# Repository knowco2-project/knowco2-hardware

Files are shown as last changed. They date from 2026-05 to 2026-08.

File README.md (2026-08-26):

# KnowCO2 Hardware

This repository contains the open hardware design files and mechanical references for the KnowCO2 indoor air quality monitor.

All original KnowCO2 hardware design files in this repository are released under the [CERN-OHL-S-2.0](LICENSE-HARDWARE) license.

## Hardware overview

The current KnowCO2 KC2-01 hardware design is built around third-party Adafruit modules and a custom KnowCO2 3D printed enclosure.

| Item | Description | Source |
|---|---|---|
| Adafruit Feather ESP32-S3 Reverse TFT | Main controller, display, Wi-Fi, USB-C power | Third-party module |
| Adafruit SCD-40/SCD-41 CO2 Sensor Breakout | CO2, temperature, and humidity sensor | Third-party module |
| STEMMA QT cable | I2C connection between Feather and sensor | Third-party cable |
| KnowCO2 enclosure | Custom 3D printed enclosure | Original KnowCO2 design files in this repository |

## Folders

| Folder | Contents |
|---|---|
| [enclosure/](enclosure/) | KnowCO2 3D enclosure design files |
| [docs/](docs/) | Documentation |
| [bom/](bom/) | Bill of materials |

## Third-party PCB/module CAD references

The Adafruit PCB/module CAD files are not maintained by KnowCO2. They are linked as mechanical references for fit checks, connector clearance, display alignment, button placement, sensor placement, and assembly planning.

- Adafruit Feather ESP32-S3 Reverse TFT:  
  https://github.com/adafruit/Adafruit_CAD_Parts/tree/main/5691%20Feather%20ESP32%20S3%20Reverse%20TFT

- Adafruit SCD-40/SCD-41 CO2 Sensor Breakout:  
  https://github.com/adafruit/Adafruit_CAD_Parts/tree/main/5187%20SCD-40%20C02%20Sensor

Third-party CAD files, board designs, product names, and trademarks remain the property of their respective owners.

## KnowCO2 enclosure files

The custom KnowCO2 enclosure files are included under [enclosure/](enclosure/).

The current enclosure design includes four printed parts:

| Part | Purpose |
|---|---|
| Main case | Main body for the Feather ESP32-S3 Reverse TFT |
| Main cover / front panel | Cover with display/button access for the main unit |
| Sensor case | Remote/secondary enclosure body for the SCD41 sensor module |
| Sensor cover | Cover for the SCD41 sensor enclosure |

## File formats

### Enclosure / 3D printed parts

| Format | Purpose |
|---|---|
| STEP (`.step` / `.stp`) | Preferred open CAD exchange format for modification and manufacturing |
| STL (`.stl`) | Print-ready mesh format for slicers |
| Shapr3D (`.shapr`) | Original source file, if included |
| PNG/JPG | Reference renders or assembly images |

For modification, import the `.step` files into a CAD tool such as FreeCAD, Shapr3D, Fusion 360, Onshape, or SolidWorks.

For printing, use the `.stl` files directly in a slicer such as PrusaSlicer, Bambu Studio, Cura, or OrcaSlicer.

### PCB / schematic

KnowCO2 KC2-01 currently uses third-party Adafruit modules rather than a custom KnowCO2 PCB. See [reference-cad/](reference-cad/) for the mechanical CAD references used by the enclosure design.

If a future KnowCO2 custom PCB is added, this repository should include open source PCB design files such as KiCad source files, Gerbers, drill files, schematic PDFs, and board STEP exports.

## Assembly notes

Before printing or assembling the enclosure, verify:

- The Feather ESP32-S3 Reverse TFT fits the main case.
- The USB-C connector is accessible.
- The TFT display aligns with the front opening.
- The buttons move freely and return properly.
- The SCD41 sensor module fits the sensor enclosure.
- The SCD41 has adequate airflow exposure.
- The STEMMA QT cable is not pinched.
- The ESP32-S3 antenna area is not blocked by metal or shielding.

## License notice (CERN-OHL-S-2.0)

This hardware is covered by the CERN Open Hardware Licence Strongly Reciprocal v2.
Full text: https://ohwr.org/cern_ohl_s_v2.txt

If you produce hardware based on these design files, you must:

- Retain this license notice and the Source Location on any product or its documentation.
- Release any modifications to the design files under the same CERN-OHL-S-2.0 license.
- Make the modified source files available, satisfying the Source requirement in CERN-OHL-S.

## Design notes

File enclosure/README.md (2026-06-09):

# KnowCO2 Enclosure

This folder contains the custom 3D printed enclosure files for the KnowCO2 KC2-01 hardware design.

The enclosure is designed around:

- Adafruit Feather ESP32-S3 Reverse TFT
- Adafruit SCD-40/SCD-41 CO2 Sensor Breakout
- STEMMA QT I2C cable
- USB-C power

The CO2 sensor is physically separated from the main electronics enclosure to improve airflow and reduce self-heating effects from the display, processor, and power circuitry.

## Parts

| Part | STEP | STL | Description |
|---|---|-----|---|
| Main case | `step/knowco2_main_case.step` | `stl/knowco2_main_case.stl` | Main body for the Feather ESP32-S3 Reverse TFT |
| Main cover | `step/knowco2_main_cover.step` | `stl/knowco2_main_cover.stl` | Front cover with display and button openings |
| Sensor case | `step/knowco2_sensor_case.step` | `stl/knowco2_sensor_case.stl` | Body for the SCD41 sensor module |
| Sensor cover | `step/knowco2_sensor_cover.step` | `stl/knowco2_sensor_cover.stl` | Cover for the SCD41 sensor enclosure |

## Images

Reference images are included in `images/`:

| Image | Description |
|---|---|
| `images/knowco2_main_case.png` | Main case reference render |
| `images/knowco2_main_cover.png` | Main cover reference render |
| `images/knowco2_sensor_case.png` | Sensor case reference render |
| `images/knowco2_sensor_cover.png` | Sensor cover reference render |

## Recommended print settings

These are starting settings and may need adjustment for your printer and filament.

| Setting | Recommendation |
|---|---|
| Material | PETG or PLA |
| Layer height | 0.20 mm |
| Nozzle | 0.4 mm |
| Infill | 15-25% |
| Walls/perimeters | 3 or more |
| Top/bottom layers | 4 or more |
| Supports | As needed based on orientation |

## Assembly checks

Before final assembly, confirm:

- The Feather ESP32-S3 Reverse TFT fits into the main case.
- The USB-C connector is accessible.
- The TFT aligns with the front cover opening.
- The buttons move freely and return properly.
- The SCD41 sensor breakout fits into the sensor case.
- The sensor has adequate airflow exposure.
- The STEMMA QT cable is not pinched.
- The ESP32-S3 antenna area is not blocked by metal or shielding.

## Notes

The STEP files are the preferred files for modification and manufacturing. The STL files are provided for direct 3D printing.

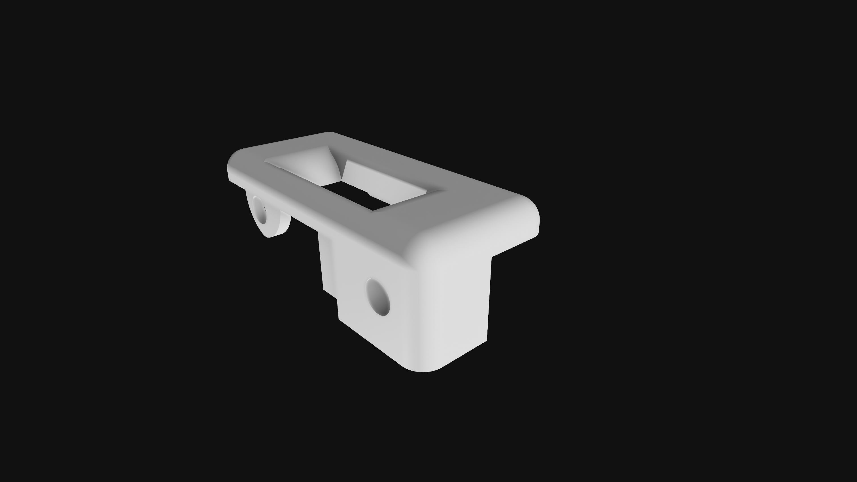
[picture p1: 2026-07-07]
enclosure/images/knowco2_main_cover.png

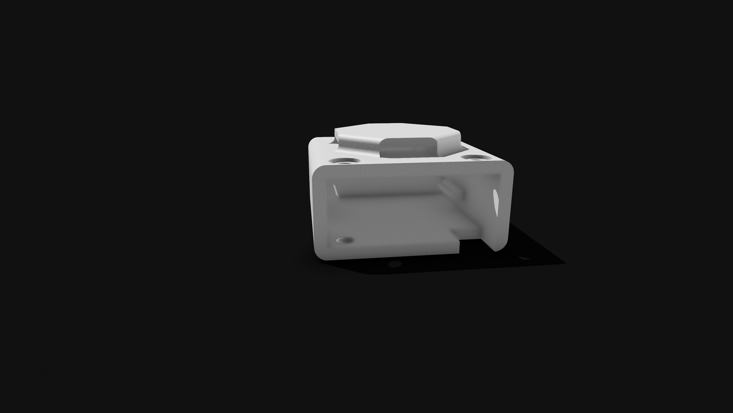
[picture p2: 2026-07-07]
enclosure/images/knowco2_sensor_case.png

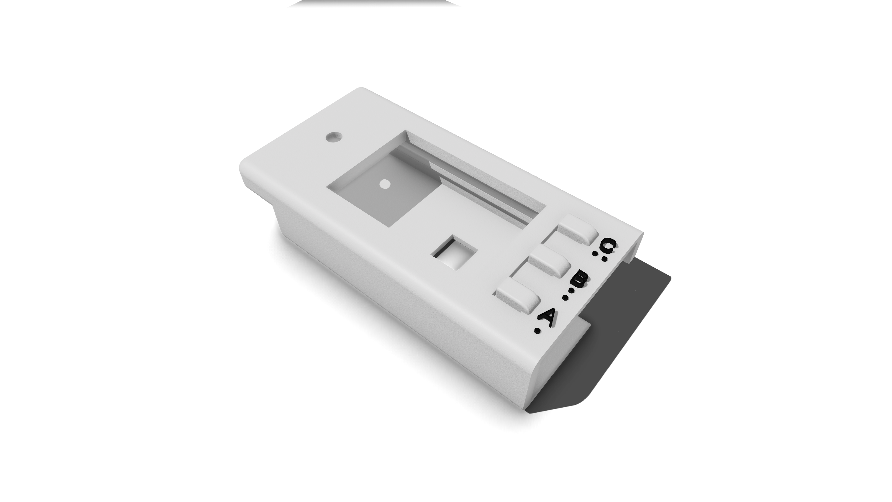
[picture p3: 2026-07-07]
enclosure/images/knowco2_main_case.png

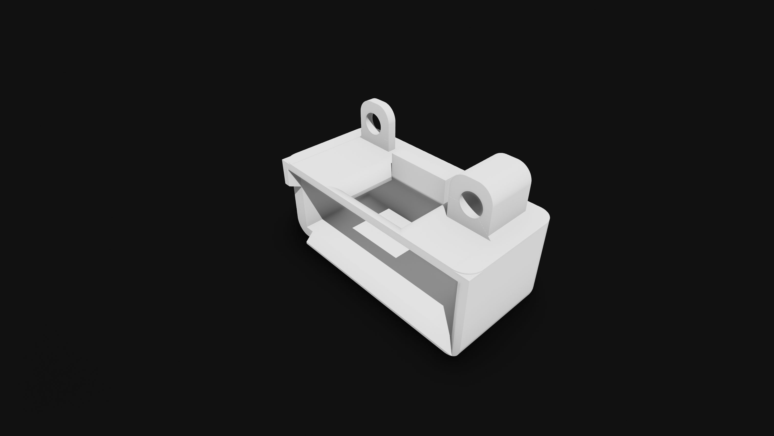
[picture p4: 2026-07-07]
enclosure/images/knowco2_sensor_cover.png

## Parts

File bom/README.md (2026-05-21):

# Bill of Materials

Hardware license: [CERN-OHL-S-2.0](../LICENSE-HARDWARE)

The BOM is provided as a CSV file: [bom.csv](bom.csv)

Columns: `Reference`, `Quantity`, `Description`, `Manufacturer`, `MPN`, `Supplier`, `Supplier PN`, `Unit Cost (USD)`, `Notes`

## No-solder build

The simplest build requires no soldering:

1. Adafruit Feather ESP32-S3 Reverse TFT
2. Sensirion SCD41 (with STEMMA QT cable)
3. STEMMA QT / Qwiic cable (50 mm or 100 mm)
4. USB-C cable (for power)
5. Printed or purchased enclosure

The sensor connects directly to the Feather via the STEMMA QT port — no soldering, no breadboard.

## Sourcing notes

- **Adafruit Feather ESP32-S3 Reverse TFT**: Available from Adafruit (#5691) and distributors (Digi-Key, Mouser)
- **Sensirion SCD40**: Lower-cost option, ±50 ppm + 5% accuracy. Available from Digi-Key (#1649-SCD40-D-R2CT-ND)
- **Sensirion SCD41**: Higher accuracy, supports single-shot measurement. Available from Digi-Key and Mouser
- **SCD30**: Older, larger sensor, dual-channel NDIR. Supported but not recommended for new builds

All primary components are available through major distributors. No specialty sourcing required.

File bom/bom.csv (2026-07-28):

Reference | Quantity | Description | Manufacturer | MPN | Supplier | Supplier PN | Unit Cost (USD) | Notes | OSHWA Certification
MCU1 | 1 | Adafruit Feather ESP32-S3 Reverse TFT | Adafruit | 5691 | Adafruit | 5691 | 24.95 | Hardware files (EagleCAD; CC-BY-SA): https://github.com/adafruit/Adafruit-ESP32-S3-Reverse-TFT-Feather-PCB | https://certification.oshwa.org/us002502.html
U1 | 1 | Adafruit SCD41 CO2/Temp/Humidity Breakout | Adafruit / Sensirion | 5190 | Adafruit | 5190 | 49.95 | Hardware files (EagleCAD; CC-BY-SA): https://github.com/adafruit/Adafruit-SCD-4x-PCB | https://certification.oshwa.org/us002089.html
CABLE1 | 1 | STEMMA QT / Qwiic Cable 50mm | Adafruit | 4399 | Adafruit | 4399 | 0.95 | Connects sensor to Feather; no soldering required | —
PWR1 | 1 | USB-C Power Supply 5V 1A UL Listed | Adafruit | 501 | Adafruit | 501 | 5.95 | UL listed; included with device | —
PWR2 | 1 | USB-C Cable | Generic | — | — | — | 5.00 | Included with device; 5V 1A minimum required | —
ENC1 | 1 | Main Unit Body (3D printed) | knowco2 | — | — | — | — | Designed by knowco2; print from hardware/enclosure/main-body.stl | https://certification.oshwa.org/us002828.html
ENC2 | 1 | Main Unit Lid (3D printed) | knowco2 | — | — | — | — | Designed by knowco2; print from hardware/enclosure/main-lid.stl | https://certification.oshwa.org/us002828.html
ENC3 | 1 | Sensor Housing Body (3D printed) | knowco2 | — | — | — | — | Designed by knowco2; print from hardware/enclosure/sensor-body.stl | https://certification.oshwa.org/us002828.html
ENC4 | 1 | Sensor Housing Lid (3D printed) | knowco2 | — | — | — | — | Designed by knowco2; print from hardware/enclosure/sensor-lid.stl | https://certification.oshwa.org/us002828.html
NUT1 | 3 | Nut M2-0.4 Coarse Thread Hexagon Carbon Steel | Generic | — | — | — | — |  | —
STND1 | 1 | Standoff M2x5mm+3mm Brass | Generic | — | — | — | — |  | —
STND2 | 2 | Standoff M2x4mm+3mm Brass | Generic | — | — | — | — |  | —
SCR1 | 1 | Screw M2-0.4 x 4mm Flat Countersunk 304 Stainless Steel | Generic | — | — | — | — |  | —
SCR2 | 1 | Screw M2-0.4 x 16mm Flat Countersunk 304 Stainless Steel A2-70 | Generic | — | — | — | — |  | —
SCR3 | 1 | Screw M2-0.4 x 6mm Flat Countersunk 304 Stainless Steel A2-70 | Generic | — | — | — | — |  | —

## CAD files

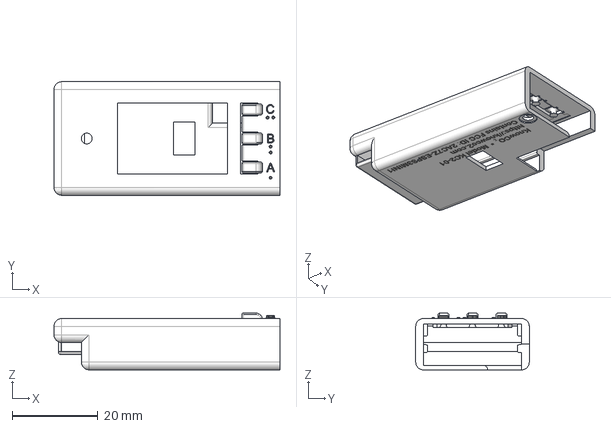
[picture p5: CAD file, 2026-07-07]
enclosure/step/knowco2_main_case.step
52.6 x 26.4 x 13.2 mm
knowco2-logo-light-mm
version1-mergedparts (Imported)

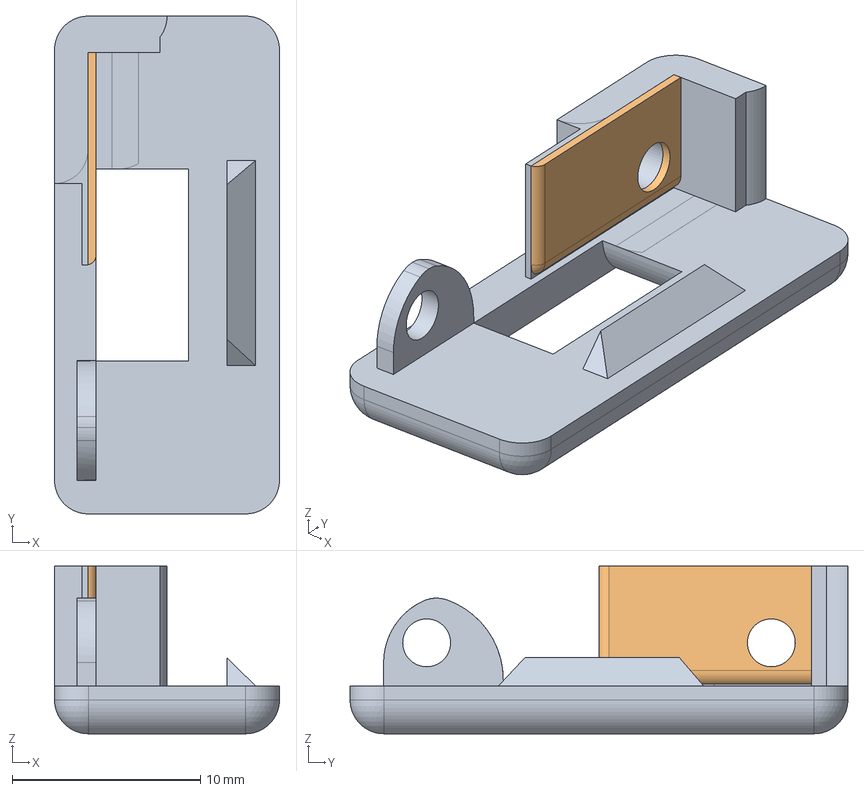
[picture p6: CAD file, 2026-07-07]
enclosure/step/knowco2_main_cover.step
11.9 x 26.4 x 8.89 mm

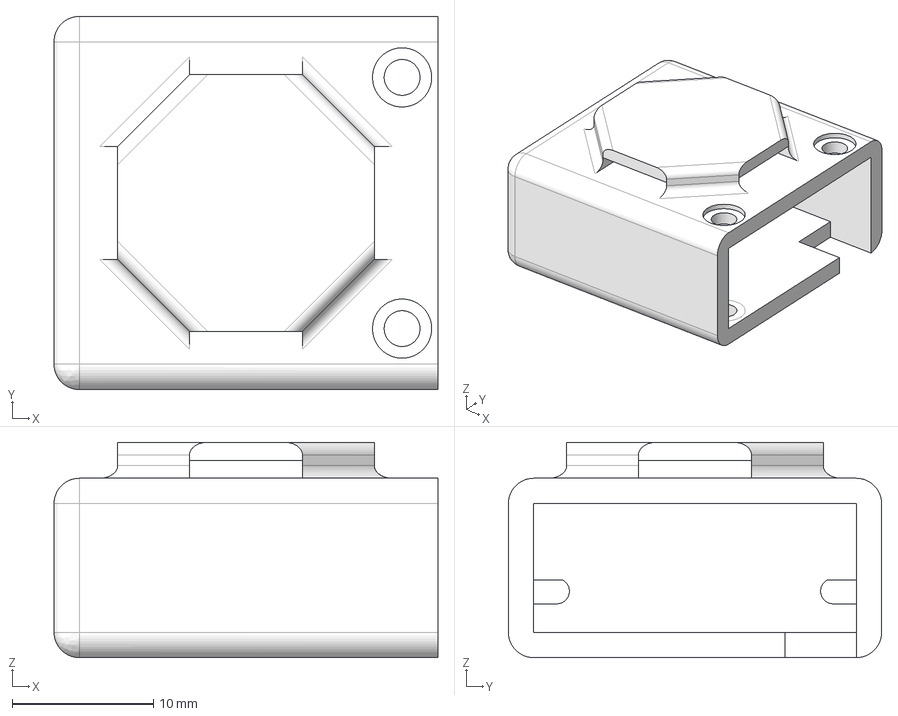
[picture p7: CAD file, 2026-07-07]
enclosure/step/knowco2_sensor_case.step
27.2 x 26.4 x 15.2 mm

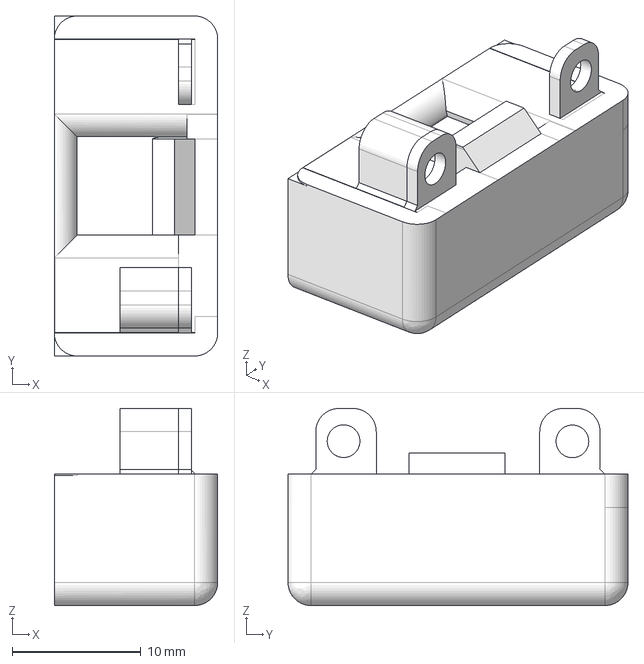
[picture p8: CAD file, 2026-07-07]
enclosure/step/knowco2_sensor_cover.step
12.7 x 26.4 x 15.3 mm

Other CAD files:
enclosure/stl/knowco2_main_case.stl
enclosure/stl/knowco2_main_cover.stl
enclosure/stl/knowco2_sensor_case.stl
enclosure/stl/knowco2_sensor_cover.stl

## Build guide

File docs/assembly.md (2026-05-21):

# Assembly Instructions

Documentation license: [CC-BY-SA-4.0](../LICENSE)

## Overview

The knowco2 device requires no soldering for the standard build. The CO₂ sensor connects to the Feather via a STEMMA QT cable, and the whole assembly slides into the 3D-printed enclosure.

**Estimated time:** 15–30 minutes (not including print time)

---

## What you need

See the full [bill of materials](../bom/bom.csv).

**Required**
- Adafruit Feather ESP32-S3 Reverse TFT
- Sensirion SCD41 breakout board
- STEMMA QT / Qwiic cable (50 mm)
- USB-C power supply
- USB-C data cable for initial setup (must support data transfer, not charge-only)
- 3D-printed enclosure (see [enclosure/](../enclosure/))

**Tools**
- Phillips head screwdriver (for enclosure screws)
- Computer with a browser (for initial setup)

---

## Step 1 — Flash CircuitPython

1. Download the latest `.uf2` for the Adafruit Feather ESP32-S3 Reverse TFT from:
   https://circuitpython.org/board/adafruit_feather_esp32s3_reverse_tft/
2. Double-tap the reset button on the Feather quickly. The board will enter the UF2 bootloader and a drive called `FTHRS3BOOT` will appear on your computer.
3. Drag the `.uf2` file onto `FTHRS3BOOT`. The board will reboot automatically.
4. A drive called `CIRCUITPY` should now appear.

> If `FTHRS3BOOT` does not appear, try double-tapping faster. The LED will turn green when in bootloader mode.

---

## Step 2 — Copy firmware files

1. Download the latest firmware release from:
   https://github.com/knowco2-project/firmware-releases/releases
2. Copy `code.py` to the root of `CIRCUITPY`
3. Copy the `lib/` folder to the root of `CIRCUITPY`
4. Safely eject the `CIRCUITPY` drive

The device will reboot and the display will show a startup screen.

---

## Step 3 — Connect the sensor

1. Connect one end of the STEMMA QT cable to the sensor breakout
2. Connect the other end to the STEMMA QT port on the Feather (the small JST SH connector on the short edge, near the USB port)

No soldering is required. The connector is keyed — it only goes in one way.

---

## Step 4 — Fit into the enclosure

1. Slide the Feather board into the main body of the enclosure with the display facing the front opening
2. Route the STEMMA QT cable and position the sensor in the sensor bay
3. Check that the three buttons (A, B, C) align with the button cutouts
4. Check that the USB-C port aligns with the side cutout
5. Fit the lid and press it closed

> The display rotation is `180°` — the board is installed upside-down relative to the Feather's silkscreen labels. This is correct.

---

## Step 5 — First power-on and Wi-Fi setup

1. Connect a USB-C cable to power the device
2. The display will show the knowco2 startup screen, then the AP info screen
3. On your phone or computer, connect to the Wi-Fi network named `knowco2-XXXX` (no password)
4. Open a browser and navigate to `http://192.168.4.1`
5. Enter your Wi-Fi network name (SSID) and password, then save
6. The device will reboot and connect to your network
7. Once connected, the Wi-Fi icon appears on the status bar

The device is now ready to use. It will be accessible on your local network at `http://knowco2-XXXX.local`.

---

## Troubleshooting

**`CIRCUITPY` drive doesn't appear after flashing**
- Check that CircuitPython was flashed successfully (step 1)
- Hold the middle button (B) while plugging in USB to force drive mode

**Device shows "No sensor" or no CO₂ readings**
- Check the STEMMA QT cable is fully seated on both ends
- Check that the cable is not pinched inside the enclosure

**Display is upside-down**
- This is normal if you are looking at the firmware source. The `display.rotation = 180` setting in `code.py` is intentional.

**Device won't connect to Wi-Fi**
- Confirm your network is 2.4 GHz (5 GHz is not supported)
- Hold the top button (C) for ~2 seconds to return to AP mode

**Sensor readings seem off after assembly**
- See the full calibration guide at [knowco2.com/calibration.html](https://knowco2.com/calibration.html)

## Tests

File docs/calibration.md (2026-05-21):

# Calibration Guide

Documentation license: [CC-BY-SA-4.0](../LICENSE)

---

## How CO₂ sensor calibration works

The Sensirion SCD4x uses Non-Dispersive Infrared (NDIR) to measure CO₂. Like all NDIR sensors, it can drift over time and benefits from periodic calibration against a known reference concentration.

Outdoor air is ~400 ppm CO₂ and is the standard reference for calibration.

---

## Automatic Self-Calibration (ASC) — recommended

ASC is enabled by default and is the recommended method for most environments.

**How it works:**
The sensor continuously tracks the lowest CO₂ level it measures. Over time, it uses that minimum as its fresh-air baseline (~400 ppm). The algorithm assumes the device is exposed to outdoor-level air at least once every few days.

**Timeline:**
- First adjustments: ~2 days of use
- Fully settled: ~7–9 days of normal use
- Runs continuously in the background

**Best practice:**
Expose the device to outdoor air for a few minutes every few days (e.g., near an open window). This gives ASC a reliable, consistent reference point.

**When NOT to use ASC:**
Disable ASC if the device is in a permanently occupied or sealed space where CO₂ never drops to outdoor levels (e.g., a sealed grow room, submarine, or server room). In these environments, ASC will drift low over time.

To disable ASC: open the settings portal at `http://knowco2-XXXX.local` and toggle Automatic Self-Calibration off.

---

## Forced Recalibration (FRC) — for immediate correction

Use FRC if readings are consistently wrong and you want to recalibrate immediately.

**Procedure:**
1. Take the device outdoors (or to a well-ventilated area with outdoor air) away from people, vehicles, and plants
2. Wait 3–5 minutes for the sensor to stabilize at the outdoor CO₂ level
3. Open the settings portal at `http://knowco2-XXXX.local`
4. Navigate to **Calibration** and enter a reference value of **415 ppm** (or the current outdoor CO₂ level from a trusted source)
5. Tap **Calibrate**

The device will apply the correction immediately. Readings should be accurate within a few minutes.

> Use a reference value of 400–420 ppm for typical outdoor air. If you have a reference instrument, use its reading as the reference value.

---

## Checking calibration

A well-calibrated device should read:
- **Outdoors:** 400–430 ppm
- **Ventilated room with no occupants:** 400–600 ppm
- **Normal occupied room:** 600–1000 ppm
- **Poorly ventilated occupied space:** 1000–2000 ppm

If readings are systematically high or low by a fixed offset, FRC is the correct remedy.

---

## SCD30 notes

The SCD30 uses a different calibration algorithm. ASC on the SCD30 requires the device to see outdoor-level CO₂ at least once every 7 days. FRC is supported via the same settings portal interface.

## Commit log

2026-05-21 add initial files and setup for 3d files
    [bom.csv]
2026-05-21 update bom
    [bom.csv]
2026-06-09 Document enclosure files and reference CAD
2026-06-09 include initial 3d models
    [knowco2-main-sensor-version-13.step, knowco2-main-sensor-version-13.stl, knowco2-main-version12.step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]
2026-06-09 Document enclosure reference images
2026-06-09 remove pcb will reference in just root readme
2026-06-18 Modify MPN and unit cost for several BOM items
    Updated manufacturer part numbers and unit costs for components.
    [bom.csv]
2026-06-19 Update bom.csv with certification links for enclosures
    Added certification links for 3D printed enclosure parts.
    [bom.csv]
2026-07-07 update to the latest version of the models, images of parts
    [knowco2_main_case.step, knowco2_main_cover.step, knowco2_main_cover.stl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]
